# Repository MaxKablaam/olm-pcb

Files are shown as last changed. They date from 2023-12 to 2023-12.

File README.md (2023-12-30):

# Olm-PCB

- [Olm-PCB](#olm-pcb)
  - [General Information](#general-information)
    - [Related Projects](#related-projects)
  - [Technologies used](#technologies-used)
  - [Usage](#usage)
  - [DIY](#diy)
    - [Controls](#controls)
  - [Project status](#project-status)
    - [Room for improvement](#room-for-improvement)
  - [Acknowledgements](#acknowledgements)
  - [Contact](#contact)
  - [License](#license)

## General Information

This repo hosts the schematics and CAD files for the PCB of the [_Olm_][olm] project.

The _Olm_ is both an interactive sculpture and a tool for randomly generating ambient soundscapes and music. It is a digital, aleatoric synthesizer housed in a hand-crafted enclosure of plywood, plaster and aluminum.

The designs enable the creation of an instrument or similar projects using the Daisy Seed. Once assembled, it supports up to three potentiometers and two switches via JST connectors. Features include USB-rechargeable battery power, a headphone amplifier, and 1/4 jack audio outputs for stereo and phones, with mono output control and outputs for LED status lights. Mono output control and LED status lights are programmable through the Daisy Seed.

olm_proc_03

### Related Projects

- [Olm][olm]
- [Olm-pd][olm-pd]

## Technologies used

- [Electro-Smith][electrosmith] [Daisy Seed][seed]
- [Adafruit PowerBoost 500 Charger][power-boost]

## Usage

The schematic files are designed in KiCad, a free and open-source PCB design tool. To view the schematics, download KiCad. PDF versions are also accessible in the repository.

For integrating the board with a pure-data patch, use the `olm_components.json` file. This file should be used when flashing the patch to the Daisy Seed with [Plugdata][plugdata] or [pd2dsy][pd2dsy].

## DIY

In the `kicad_project/Export` folder, you'll find all necessary files for manufacturing the board. I successfully used these files to produce the board at an affordable cost with [JLCPCB][jlc].

### Controls

- **Potentiometers**: Use a linear 10K potentiometer. Attach its leads to a 3-pin JST PH connector as shown in the schematics.
- **Switches**: Any simple two-lead switch will work, though I used [Kailh Box Jade keyboard switches](https://www.kailh.net/products/kailh-box-thick-clicky-switch-set). Connect the leads to a 2-pin JST PH connector, the connection order doesn't matter.
- **Cabling**: You can create custom cables using heat-shrink tubing, which can be integrated into any unique enclosure you design.

DPOiuQq8q8

## Project status

Project is _Complete_!

### Room for improvement

While the PCB aspect of the _Olm_ project is finished, there are always things that can be improved upon in future projects.

- **Headphone Amplifier**: The existing design is outdated and could be enhanced in future versions.
- **Surface-Mount Technology (SMT)**: The use of Through-Hole Technology (THT) was a personal choice due to my unfamiliarity with SMT and not wanting to acquire any more new tools or skills for this complex project. However, retrospectively, SMT might have simplified the process. Future projects will likely adopt SMT.
- **Rechargeable Battery Implementation**: This version employs the [Adafruit Power Boost 500][power-boost] daughter-board for battery charging. For future designs, I plan to integrate a simpler, custom charger directly onto the PCB, which would be more cost-effective and space-efficient.

## Acknowledgements

This project owes its success to the dedication of the Daisy Seed engineers and the invaluable support of their communities. Special acknowledgments go to:

- [Daisy Seed Discord][daisy-discord]
<!-- - Takumi Ogata: That helpful dude on the daisy seed discord, for his help, and tutorials TODO -->

PCB assembled

## Contact

Created by [Eric Max Kaplin][me].

## License

This project is open source and unless otherwise specified in specific files, available under the [GPL-3 License][license].

[olm]: https://ericmaxkaplin.com/content/projects/olm/
[olm-pd]: https://github.com/MaxKablaam/olm-pd
[electrosmith]: https://www.electro-smith.com/
[seed]: https://www.electro-smith.com/daisy/daisy
[power-boost]: https://www.adafruit.com/product/1944
[jlc]: https://jlcpcb.com/
[plugdata]: https://plugdata.org/
[pd2dsy]: https://github.com/electro-smith/pd2dsy
[daisy-discord]: https://discord.gg/ByHBnMtQTR
[license]: https://www.gnu.org/licenses/gpl-3.0.en.html
[me]: https://ericmaxkaplin.com/

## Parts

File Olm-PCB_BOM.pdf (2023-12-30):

12/29/2023

# Olm-PCB BOM

# Reference | Qty Value | Footprint

1 | A1 | 1 | Electrosmith Daisy Seed Rev4 | UserLibrary:Electrosmith_Daisy_Seed
2 | A2 | 1 | Adafruit PowerBoost 500C | UserLibrary:PowerBoost 500C
3 | C1, C3, C4 | 3 | 0.01uF | Capacitor_THT:C_Disc_D4.7mm_W2.5mm_P5.00mm
4 | C2, C11, C12 | 3 | 0.1uF | Capacitor_THT:C_Disc_D4.7mm_W2.5mm_P5.00mm
5 | C5, C6, C7, C9 | 4 | 10uF | Capacitor_THT:CP_Radial_D4.0mm_P2.00mm
6 | C8, C10 | 2 | 220uF | Capacitor_THT:CP_Radial_D6.3mm_P2.50mm
7 | J1, J2, J3, J4 | 4 | JST B3B-PH-K | Connector_JST:JST_PH_B3B-PH-K_1x03_P2.00mm_Vertical
8 | J5, J6 | 2 | JST B2B-PH-K | Connector_JST:JST_PH_B2B-PH-K_1x02_P2.00mm_Vertical
9 | J7 | 1 | JST B5B-PH-K | Connector_JST:JST_PH_B5B-PH-K_1x05_P2.00mm_Vertical
10 | J8 | 1 | NMJ6HCD2 | UserLibrary:Jack_6.35mm_Neutrik_NMJ6HCD2_Horizontal
11 | J9, J10 | 2 | NMJ4HCD2 | UserLibrary:Jack_6.35mm_Neutrik_NMJ4HCD2_Horizontal
12 | J11, J20 | 2 | JST PH-R-2
13 | J12 | 1 | Conn_01x08_Socket | Connector_PinSocket_2.54mm:PinSocket_1x08_P2.54mm_Vertical
14 | J13, J15, J17, J19 | 4 | JST PH-R-3
15 | J14, J16 | 2 | Conn_01x20_Socket | Connector_PinSocket_2.54mm:PinSocket_1x20_P2.54mm_Vertical
16 | J18 | 1 | JST PH-R-5
17 | J21, J22 | 2 | DIP-8 Socket | Package_DIP:DIP-8_W7.62mm_Socket
18 | Q1 | 1 | IRF9540N | Package_TO_SOT_THT:TO-220-3_Vertical
19 | R1 | 1 | 330K | Resistor_THT:R_Axial_DIN0207_L6.3mm_D2.5mm_P7.62mm_Horizontal
20 | R2 | 1 | 1M | Resistor_THT:R_Axial_DIN0207_L6.3mm_D2.5mm_P7.62mm_Horizontal
21 | R3 | 1 | 20K | Resistor_THT:R_Axial_DIN0207_L6.3mm_D2.5mm_P7.62mm_Horizontal
22 | R4, R5 | 2 | 18K | Resistor_THT:R_Axial_DIN0207_L6.3mm_D2.5mm_P7.62mm_Horizontal
23 | R6, R7 | 2 | 10 | Resistor_THT:R_Axial_DIN0207_L6.3mm_D2.5mm_P7.62mm_Horizontal
24 | R8, R9 | 2 | 100 | Resistor_THT:R_Axial_DIN0207_L6.3mm_D2.5mm_P7.62mm_Horizontal
25 | RV1, RV2, RV3, RV4 | 4 | B10K Pot | UserLibrary:Potentiometer_Alps_RK163_Single_Horizontal
26 | RV5 | 1 | RK10J12E002L | UserLibrary:RK10J12E002L
27 | SW1 | 1 | Adafruit PM162-K
28 | SW2, SW3 | 2 | Kailh Box Jade Switch
29 | U1, U2 | 2 | LM386 | Package_DIP:DIP-8_W7.62mm

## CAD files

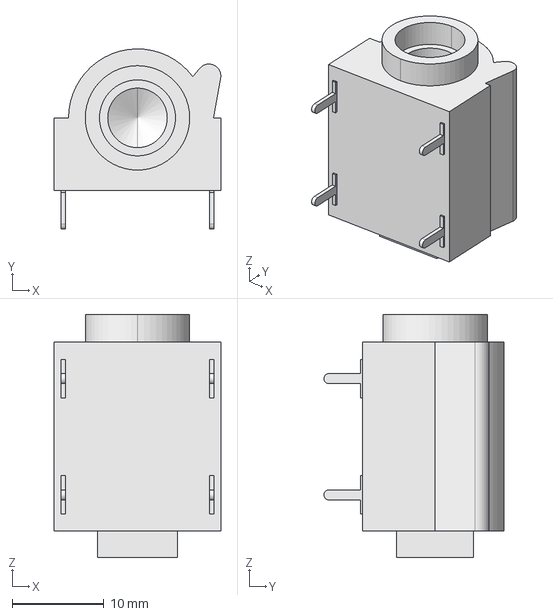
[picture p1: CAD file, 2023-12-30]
kicad_project/CAD/Neutrik/NMJ4HCD2_Neutrik_AudioJack-D-NMJ4HCD2.step
18.2 x 19.7 x 26.5 mm

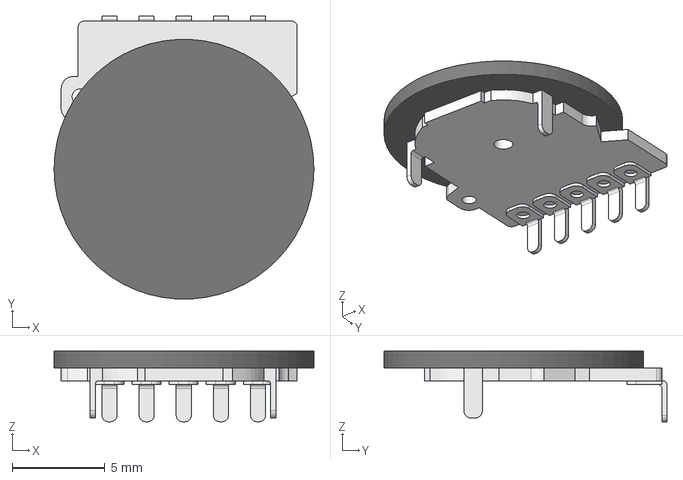
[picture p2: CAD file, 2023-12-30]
kicad_project/CAD/RK10J12E002L.step
14.0 x 15.2 x 3.80 mm

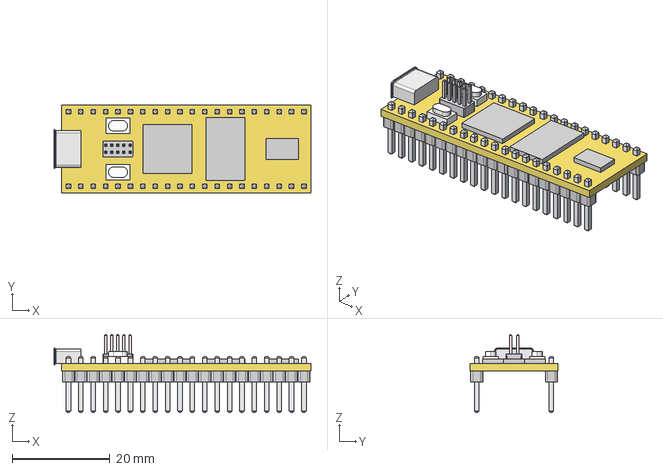
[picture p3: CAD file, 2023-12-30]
kicad_project/CAD/seed/Daisy Seed.iges
52.7 x 18.1 x 16.0 mm

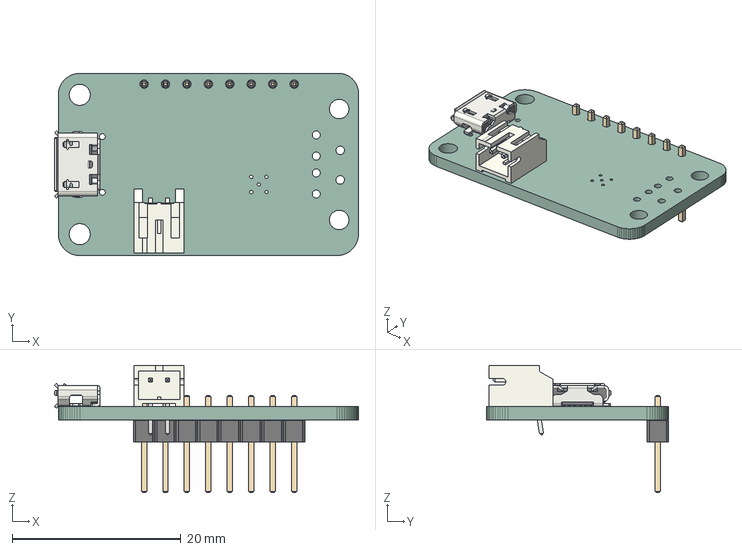
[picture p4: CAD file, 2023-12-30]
kicad_project/CAD/Adafruit PowerBoost 500C.step
36.0 x 21.6 x 15.1 mm
_autosave-Adafruit PowerBoost 500C PCB

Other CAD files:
kicad_project/CAD/Neutrik/3-D NMJ6HCD2.stp
kicad_project/CAD/seed/Daisy Seed.f3d
kicad_project/CAD/seed/Daisy Seed.skp

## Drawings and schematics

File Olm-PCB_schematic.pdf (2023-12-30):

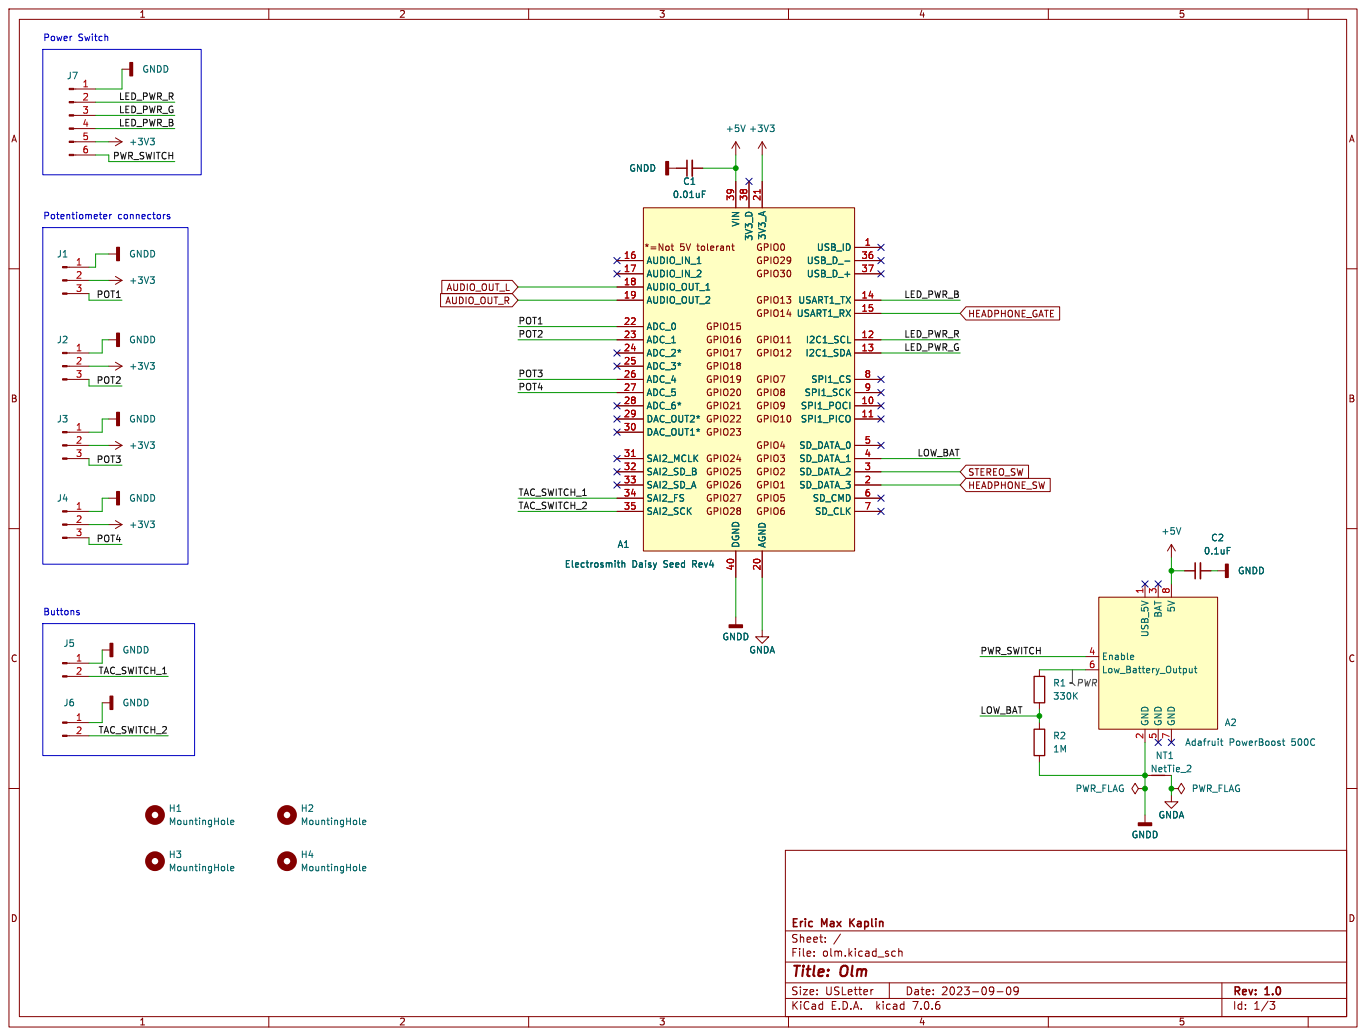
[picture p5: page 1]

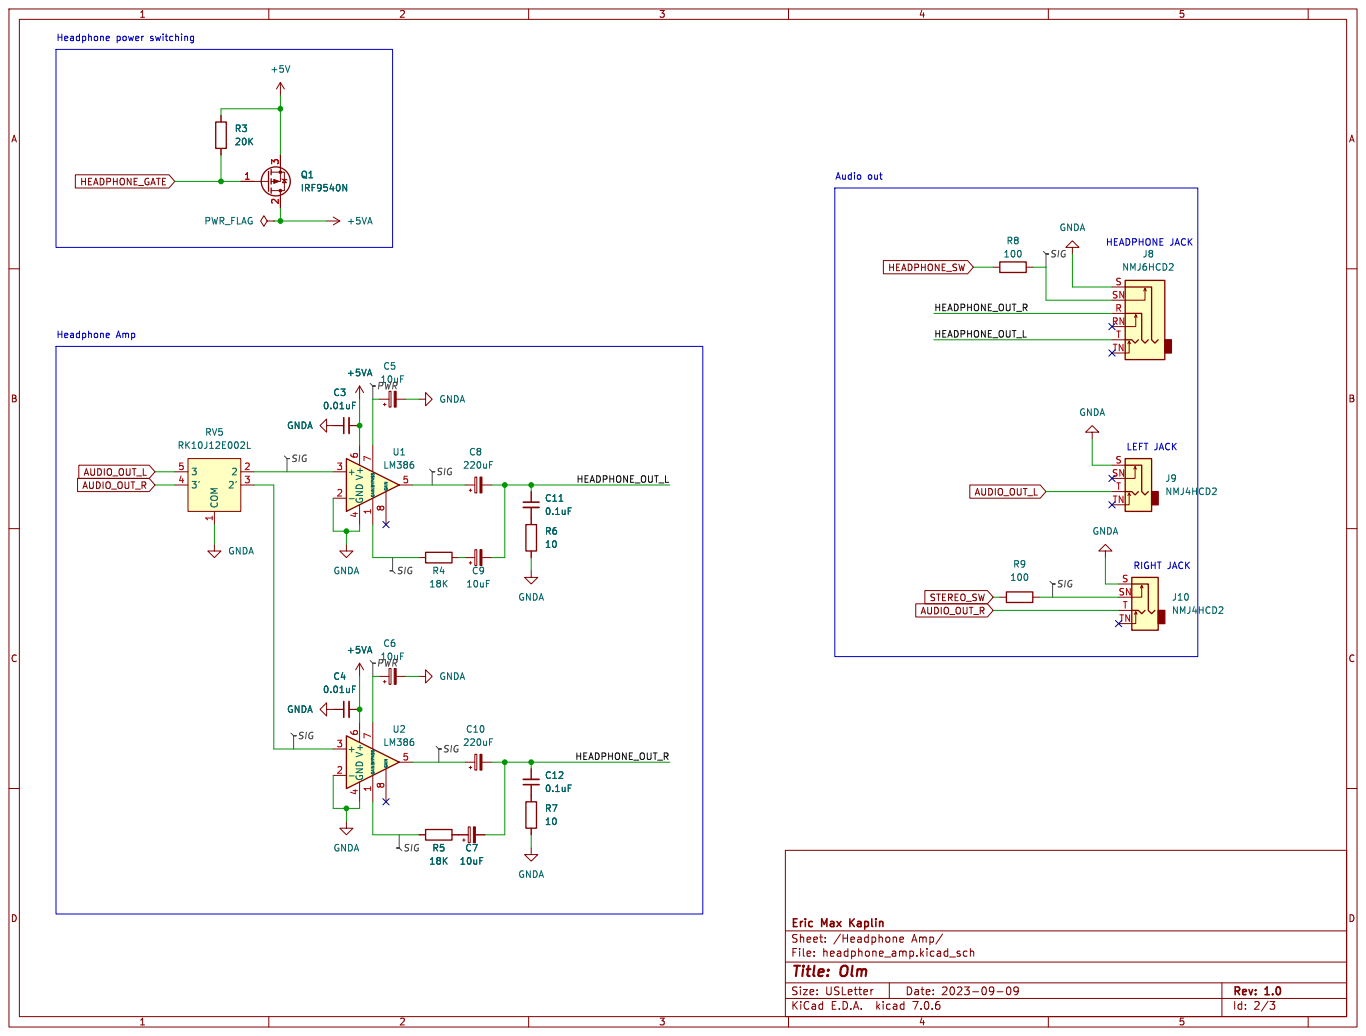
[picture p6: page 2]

SW3 Kailh Box Jade Switch GNDA C7

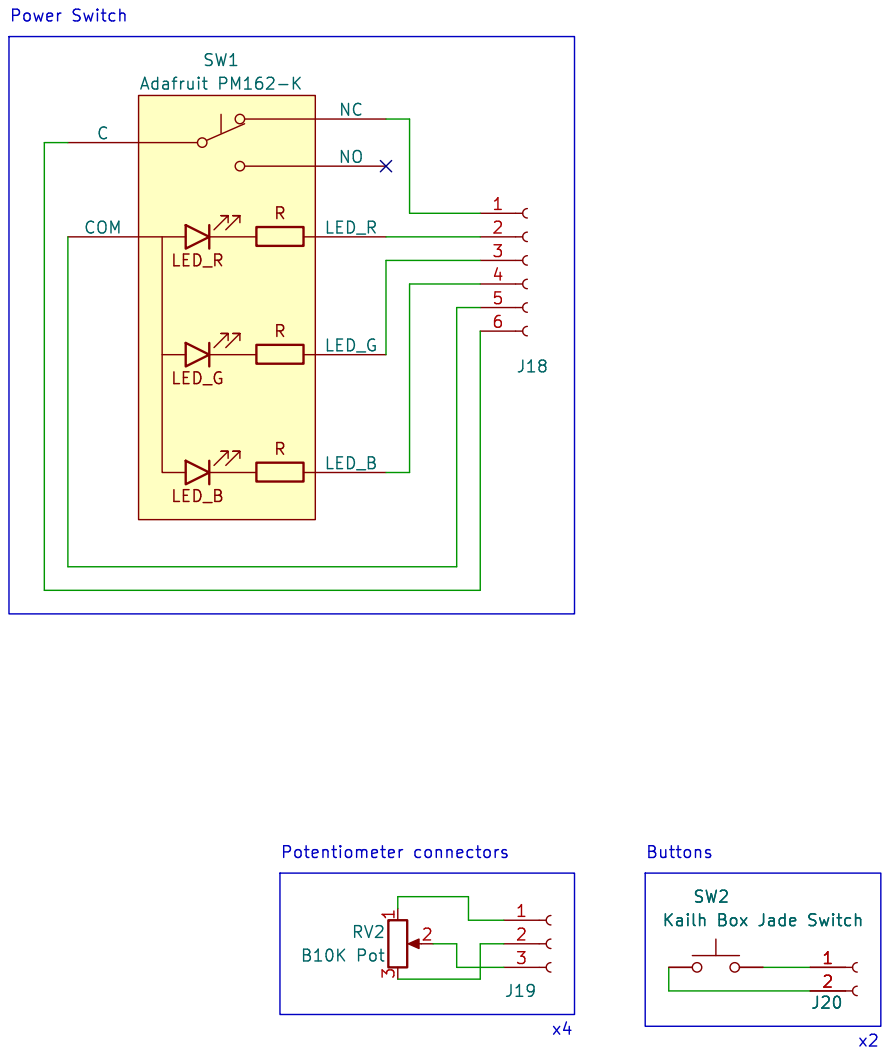
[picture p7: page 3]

SW2 Kailh Box Jade Switch

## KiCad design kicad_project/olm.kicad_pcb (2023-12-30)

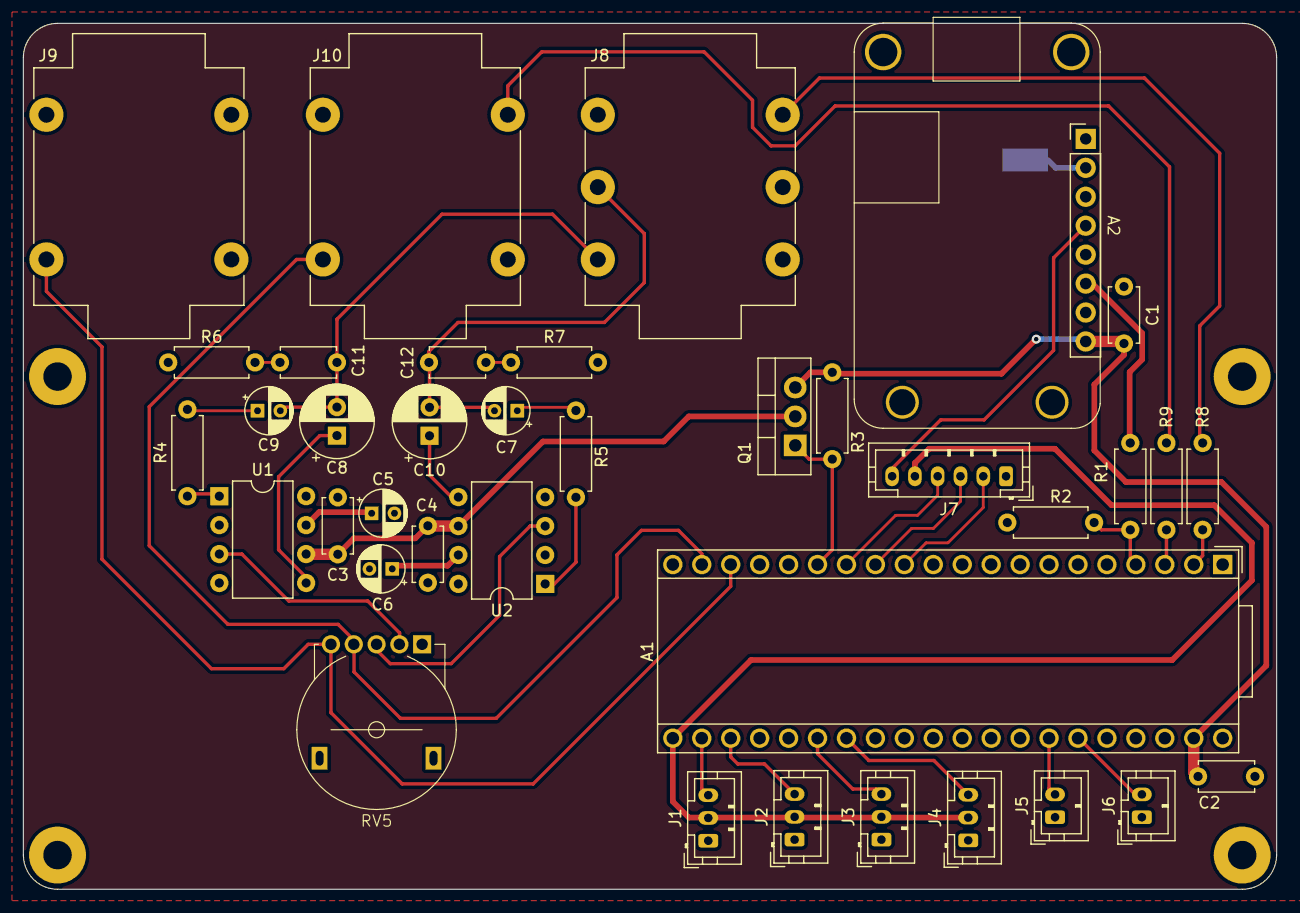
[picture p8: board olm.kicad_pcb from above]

Board: 2 copper layers, 110.0 x 76.0 mm, 42 parts (1 on the bottom side), 38 nets.

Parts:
A1: Electrosmith Daisy Seed Rev4; Electrosmith_Daisy_Seed
A2: Adafruit PowerBoost 500C; PowerBoost 500C
C1, C3, C4: 0.01uF; C_Disc_D4.7mm_W2.5mm_P5.00mm
C2, C11, C12: 0.1uF; C_Disc_D4.7mm_W2.5mm_P5.00mm
C5, C6, C7, C9: 10uF; CP_Radial_D4.0mm_P2.00mm
C8, C10: 220uF; CP_Radial_D6.3mm_P2.50mm
H1, H2, H3, H4: MountingHole; MountingHole_2.5mm_Pad
J1, J2, J3, J4: JST B3B-PH-K; JST_PH_B3B-PH-K_1x03_P2.00mm_Vertical
J5, J6: JST B2B-PH-K; JST_PH_B2B-PH-K_1x02_P2.00mm_Vertical
J7: JST B5B-PH-K; JST_PH_B6B-PH-K_1x06_P2.00mm_Vertical
J8: NMJ6HCD2; Jack_6.35mm_Neutrik_NMJ6HCD2_Horizontal
J9, J10: NMJ4HCD2; Jack_6.35mm_Neutrik_NMJ4HCD2_Horizontal
NT1: NetTie_2; NetTie-2_SMD_Pad2.0mm
Q1: IRF9540N; TO-220-3_Vertical
R1: 330K; R_Axial_DIN0207_L6.3mm_D2.5mm_P7.62mm_Horizontal
R2: 1M; R_Axial_DIN0207_L6.3mm_D2.5mm_P7.62mm_Horizontal
R3: 20K; R_Axial_DIN0207_L6.3mm_D2.5mm_P7.62mm_Horizontal
R4, R5: 18K; R_Axial_DIN0207_L6.3mm_D2.5mm_P7.62mm_Horizontal
R6, R7: 10; R_Axial_DIN0207_L6.3mm_D2.5mm_P7.62mm_Horizontal
R8, R9: 100; R_Axial_DIN0207_L6.3mm_D2.5mm_P7.62mm_Horizontal
RV5: RK10J12E002L
U1, U2: LM386; DIP-8_W7.62mm

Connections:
+3V3: A1.21 (3V3_A), J1.2, J2.2, J3.2, J4.2, J7.5
+5V: A1.39 (VIN), A2.8 (5V), C1.2, C2.1, Q1.3 (S), R3.2
+5VA: C3.2, C4.2, Q1.2 (D), U1.6 (V+), U2.6 (V+)
/Headphone Amp/HEADPHONE_OUT_L: C8.2, C9.2, C11.1, J8.T
/Headphone Amp/HEADPHONE_OUT_R: C7.2, C10.2, C12.2, J8.R
/LED_PWR_B: A1.14 (USART1_TX), J7.4
/LED_PWR_G: A1.13 (I2C1_SDA), J7.3
/LED_PWR_R: A1.12 (I2C1_SCL), J7.2
/LOW_BAT: A1.4 (SD_DATA_1), R1.2, R2.1
/POT1: A1.22 (ADC_0), J1.3
/POT2: A1.23 (ADC_1), J2.3
/POT3: A1.26 (ADC_4), J3.3
/POT4: A1.27 (ADC_5), J4.3
/PWR_SWITCH: A2.4 (Enable), J7.6
/TAC_SWITCH_1: A1.34 (SAI2_FS), J5.2
/TAC_SWITCH_2: A1.35 (SAI2_SCK), J6.2
AUDIO_OUT_L: A1.18 (AUDIO_OUT_1), J9.T, RV5.5 (3)
AUDIO_OUT_R: A1.19 (AUDIO_OUT_2), J10.T, RV5.4 (3')
GNDA: A1.20 (AGND), C3.1, C4.1, C5.2, C6.2, J8.S, J9.S, J10.S, NT1.2, R6.2, R7.2, RV5.1 (COM), U1.2 (-), U1.4 (GND), U2.2 (-), U2.4 (GND)
GNDD: A1.40 (DGND), A2.2 (GND), C1.1, C2.2, J1.1, J2.1, J3.1, J4.1, J5.1, J6.1, J7.1, NT1.1, R2.2
HEADPHONE_GATE: A1.15 (USART1_RX), Q1.1 (G), R3.1
HEADPHONE_SW: A1.2 (SD_DATA_3), R8.1
unnamed: A2.6 (Low_Battery_Output), R1.1
unnamed: C7.1, R5.2
unnamed: C8.1, U1.5
unnamed: C9.1, R4.2
unnamed: C10.1, U2.5
unnamed: C11.2, R6.1
unnamed: C12.1, R7.1
unnamed: J8.SN, R8.2
unnamed: J10.SN, R9.1
unnamed: R4.1, U1.1 (GAIN)
unnamed: R5.1, U2.1 (GAIN)
unnamed: RV5.3 (2'), U2.3 (+)
unnamed: RV5.2, U1.3 (+)
unnamed: C5.1, U1.7 (BYPASS)
unnamed: C6.1, U2.7 (BYPASS)
STEREO_SW: A1.3 (SD_DATA_2), R9.2
